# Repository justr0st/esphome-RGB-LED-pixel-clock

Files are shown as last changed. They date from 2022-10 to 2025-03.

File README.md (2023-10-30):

# Pixel clock for ESPhome

Simple ESPHome pixel clock based on WS2812b lightstrip with 17x5 display. 
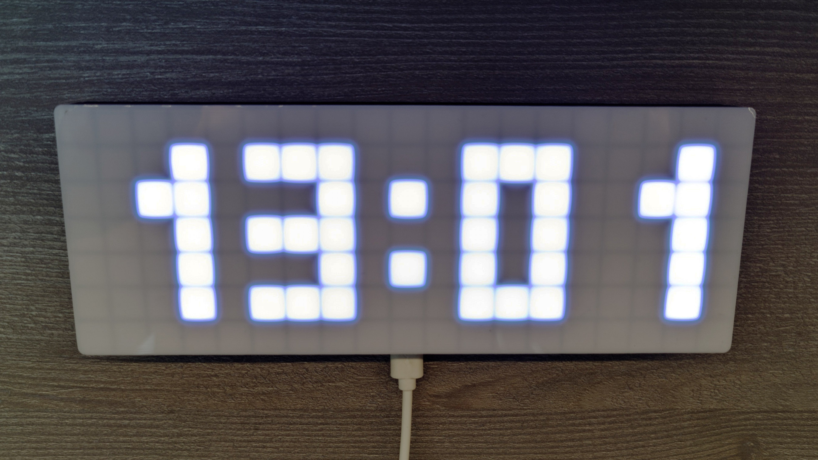
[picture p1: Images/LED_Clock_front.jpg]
front

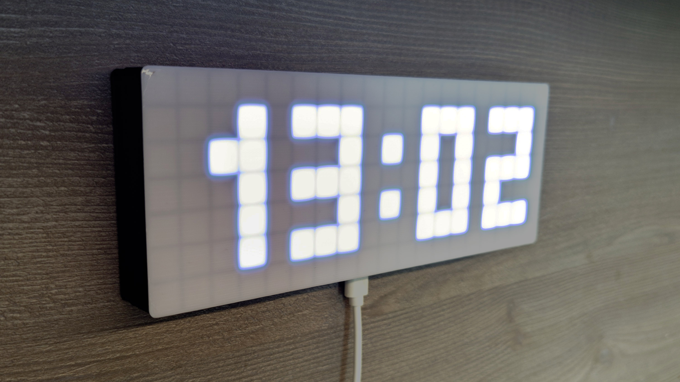
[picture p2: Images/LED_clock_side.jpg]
side


## Preparation
Materials needed:
  * Wemos D1 Mini ([example](https://www.amazon.de/gp/product/B0754N794H/))
  * WS2812b LED strip IPx0 without protective coating (100 LEDs/m) ([example](https://www.amazon.de/gp/product/B088FJLRFP))
  * 1x resistor from 220 Ω to 470 Ω
  * some wires and soldering iron
  * 6x M3x10 screws

  1. Print all three STL files. They could be printed completely using white plastic. Or change the material to black color after printing 1 mm of 'clock screen.STL' if you like it in such way, as i did it.
  2. Cut the WS2812b LED strip into 5 strips with 17 LEDs each and solder everything according to wiring diagram:
     wiring
  3. Put the strips into the sockets into printed display and pull the wire through the hole in the middle frame. Connect the board, bend the wires and close the case.
  
## Installation

Already installed and running ESPHome is needed. For more info see [Getting started with ESPHome](https://esphome.io/guides/getting_started_hassio.html).

1. Copy contents of ./esphome ('**led-clock.yaml**, '**secrets.yaml**' and '**animations**' directory) to ESPhome configurations location. If you already have '**secrets.yaml**', then just edit it accordingly.

   Usually esphome path is:
   ```
   /usr/share/hassio/homeassistant/esphome
   ```
2. Edit '**secrets.yaml**' by entering your **wifi_ssid**, **wifi_password**, **ota_password** and **api_encryption_key**.

   **ota_password** is just a key that will be needed to be able to update the clock device wirelessly over the air afterwards.
   
   **api_encryption_key** Is a unique BASE64 key which can be generated [here](https://esphome.io/components/api.html#configuration-variables):

   

3. Edit **manual_ip:** subsection of **wifi:** section in 'led-clock.yaml' and enter the IP configuration for your clock.

   If you prefer dynamic IP assigned by your router, you can just comment those lines out using '#' symbol:
   ```yaml
   #      static_ip: 192.168.1.222
   #      gateway: 192.168.1.1
   #      subnet: 255.255.255.0
   ```

4. After opening ESPHome user interface you will a new device called "led-clock" will be available:

   

   Press "EDIT" button you to see the yaml code.
   
6. Connect the board to your PC using USB and install the firmware:

   **INSTALL > Plug into this computer**

   Wait untill firmware will be prepared and follow the on-screen instructions.

   Afterwards it will be possible to do future firmware updates wirelessly via OTA.

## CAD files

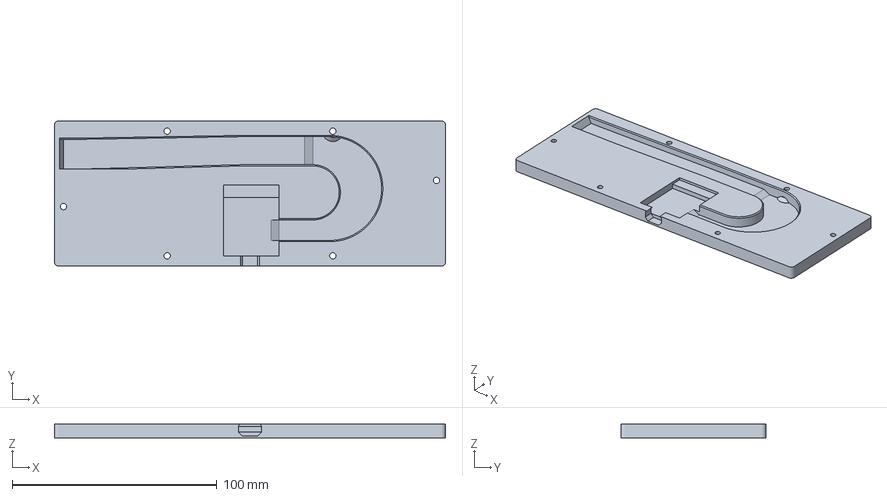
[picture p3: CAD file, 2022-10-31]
STLs and CAD/clock back.3mf
190.8 x 70.8 x 7.00 mm

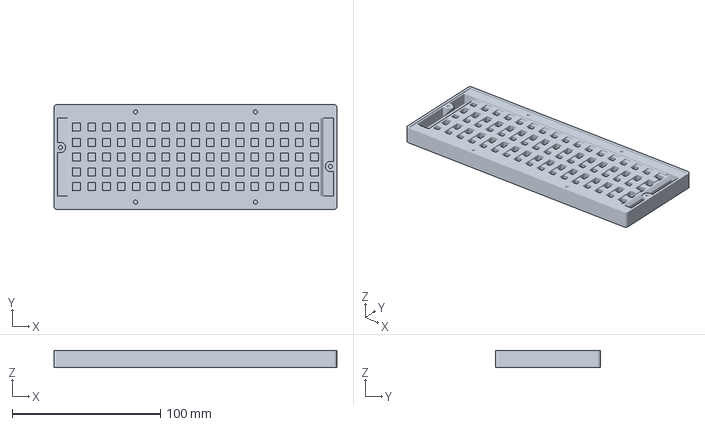
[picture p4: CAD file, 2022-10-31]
STLs and CAD/clock screen.3mf
190.8 x 70.8 x 11.6 mm

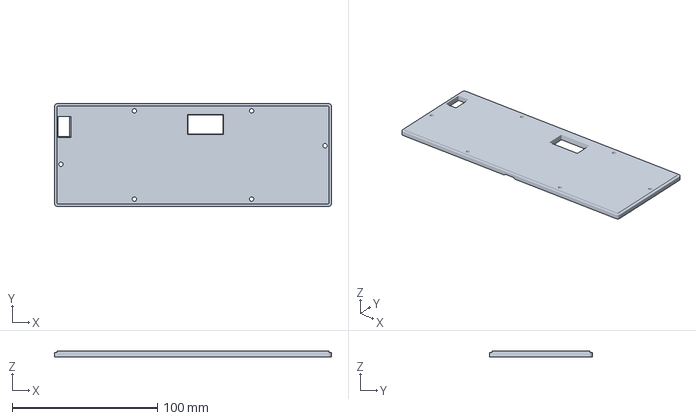
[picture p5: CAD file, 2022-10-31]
STLs and CAD/clock body.3mf
190.8 x 70.8 x 3.80 mm

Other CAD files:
STLs and CAD/clock back.stl
STLs and CAD/clock body.stl
STLs and CAD/clock screen.stl

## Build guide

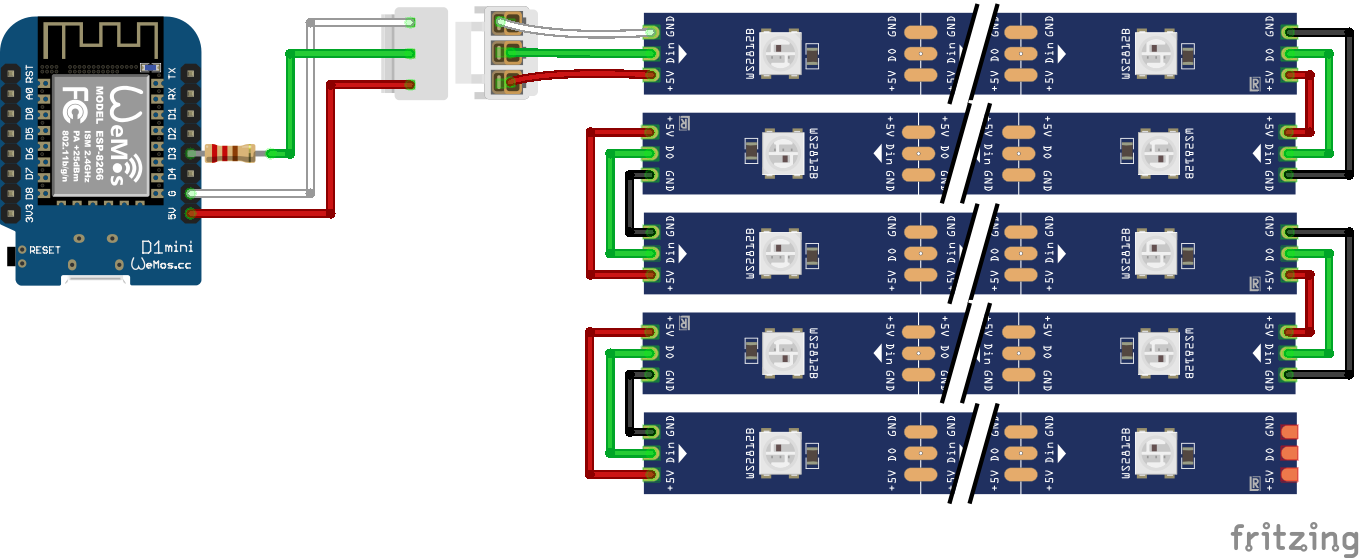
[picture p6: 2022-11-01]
Images/Wiring Sketch.png

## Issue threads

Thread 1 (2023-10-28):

Vertical mode and Custom metrix.

kubert96, 2023-10-28:
Helloooo :)

Great Project.

Is there way to edit this to suport custom metrix?

I am triing to edit code to work on 11x7 vertical metrix.

So my output would be:
1 0. -- Hours
2 3 -- Minutes
Without devider.

Bitmat is OK its working and code to but i cant understand how to edit to work in vertical.

Thanks for great project :)

justr0st, 2023-10-30:
Hello there!
Thanks for the appreciation and following the project!

First of all, I think you mean the matrix 7x11 (horizonal x vertical pixels), right? Then you heed to redefine the display matrix in "display" section by changing width and height accordingly.
Second thing to do is finding out, what exactly your matrix is and how your pixels are mapped. In case you have followed my project and also went using adressable led light, you don't need to change the platform. However it is very important to set the pixel_mapper correct. If your every second row has inverse pixel order like mine, then it should be enough to change 17->7 and 16->6 in the pixel_mapper.
```
  display:
    - platform: addressable_light
      id: led_matrix_display
      addressable_light_id: led_matrix
      width: 7
      height: 11
      pixel_mapper: |-
        if (y % 2 == 0) {
          return (y * 7) + x;
        }
        return (y * 7) + (6 - x);
```
However if your strips are vertical or in some other order, you should do some math 🙂. See [ESPHome Adressable Light](https://esphome.io/components/display/addressable_light.html) for reference.

I changed the code in the YAML today so the next things you will need are now already supported:

1. Update the digits coordinates in digit_location_X and digit_location_Y arrays. They are the coordinates of the upper left pixel of each digit. In your case i think it should be like that:
```
          const int digit_location_X[digitsCount] = {0, 4, 0, 4};
          const int digit_location_Y[digitsCount] = {0, 0, 6, 6};
```

2. Disable colon symbol:
```
          const bool enableColon = false;`
```

I think that schould do.

kubert96, 2023-10-30:
Oh great. This works.

Thanks for the expenation :)

justr0st, 2023-10-30:
You are welcome :)

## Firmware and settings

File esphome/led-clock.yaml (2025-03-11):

substitutions:
  name: led-clock

esphome:
  name: ${name}
  min_version: 2025.2.1
  on_boot:
    then:
      - display.page.show: splashscreen
      - light.turn_on: 
          id: clock_rgb
          brightness: 50%

esp8266:
  board: d1_mini

wifi:
  ssid: !secret wifi_ssid
  password: !secret wifi_password
  
  manual_ip:
    static_ip: 192.168.1.222
    gateway: 192.168.1.1
    subnet: 255.255.255.0

  # Enable fallback hotspot (captive portal) in case wifi connection fails
  ap:
    ssid: "&{name} Fallback"
    password: !secret ota_password
    channel: 4

captive_portal:

# Enable logging
logger:

# Enable Home Assistant API
api:
  encryption:
    key: !secret api_encryption_key

ota:
  platform: esphome
  password: !secret ota_password

time:
 # - platform: homeassistant
 #   id: homeassistant_time
  - platform: sntp
    id: sntp_time
    timezone: "Europe/Berlin"
    servers:
      - 0.pool.ntp.org
      - 1.pool.ntp.org
      - 2.pool.ntp.org
    on_time_sync:
      then:
        - globals.set:
            id: time_synced
            value: 'true'
        - if:
            condition:
              lambda: 'return id(time_synced);'
            then:
              - lambda: |-
                  auto time = id(sntp_time).now();
                  id(previousTimeValue)[0] = time.hour / 10;
                  id(previousTimeValue)[1] = time.hour % 10;
                  id(previousTimeValue)[2] = time.minute / 10;
                  id(previousTimeValue)[3] = time.minute % 10;
              - display.page.show: clock_page

globals:
  - id: red_value
    type: int
    restore_value: yes
    initial_value: '50'

  - id: green_value
    type: int
    restore_value: yes
    initial_value: '50'

  - id: blue_value
    type: int
    restore_value: yes
    initial_value: '50'
  
  - id: time_synced
    type: bool      
    restore_value: no
    initial_value: 'false'

  - id: digit_animationStart
    type: bool[4]
    restore_value: no
    initial_value: '{false, false, false, false}'

  - id: previousTimeValue
    type: int[4]
    restore_value: no
    initial_value: '{0, 0, 0, 0}'
  
  - id: digit_animationFrame
    type: int
    restore_value: no
    initial_value: '0'

output:
  - platform: template
    id: red_output
    type: float
    min_power: 0.2
    write_action:
      lambda: |-
        id(red_value) = 255.0 * state;

  - platform: template
    id: green_output
    type: float
    min_power: 0.2
    write_action:
      - lambda: |-
          id(green_value) = 255.0 * state;

  - platform: template
    id: blue_output
    type: float
    min_power: 0.2
    max_power: 0.95
    write_action:
      lambda: |-
        id(blue_value) = 255.0 * state;

animation:
  - file: "animations/Kotik.gif"
    id: kotik_animation
    type: RGB
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

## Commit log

2022-10-21 Color calibration tweaks & higher display refresh rate
2022-10-23 change GPIO2 -> GPIO4 to prefent leds to turn on during boot
2022-10-26 - fixed transition animation 3->0
    [led-clock.yaml]
2022-10-31 - moved project data to ./esphome/ - added STL files for 3D print - added F3D file for Fusion 360
    [Font.xlsx, clock back.3mf, clock back.stl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]
2022-11-01 - added wiring sketch
2022-11-01 - added wiring sketch in SVG
2022-11-01 - fixed wiring sketch SVG
2023-07-05 Update README.md
    Added resistor to parts list
2023-10-30 Support for 2D digit positioning; Switch for colon symbol
    - Added possibility to change also the Y coordinate for each digit
    - Added enabler/disabler for colon symbol
2023-10-30 Replace API password with encryption key (#2)
    * Added 'api_encryption_key' entry
    Added 'api_encryption_key' entry because old Home Assistant API password is deprecated.
    * Replaced API password with encryption key
    API password is deprecated. Switched to encryption key.
    * Update README.md to include changes to API key
    [led-clock.yaml]
2025-01-07 led-clock.yaml : renamed 'tyme_synced' (lol) into 'time_synced'
2025-03-11 Update led-clock.yaml to be compatible with ESPHome 2025.2.1
2025-03-11 Update led-clock.yaml min_version
